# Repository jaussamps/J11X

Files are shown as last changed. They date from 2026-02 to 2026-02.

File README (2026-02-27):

     This is a basic analog test rig for J112/3 JFETs, for determining
     V_GS(off) and I_DSS of specific samples. The design can easily be
     modified to test other N-type depletion-mode families by changing
     power rails, etc. as needed to account for their characteristics.

     As always, this design is free for you to use as you see fit, but
     you do so at your own risk: I provide no warranties of any kind.

                                     --- Charles E. Youse (@jaussamps)

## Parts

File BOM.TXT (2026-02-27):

BILL OF MATERIALS ----------------  J11X  ------------------------ REV A 02/26

C1-C4           220uF 16V 20% ELEC      VALUEPRO ECA-1CM221-JVP
                (6.3 x 11 x 2.5mm)      [JC:198872]

F1              FUSE 30mA 250V PTC      YAGEO BK250-030-DZ
                                        [DK:13-BK250-030-DZ-ND]

D1,D2           1N4007                  [JC:36011]

D3              LED 30mA 2.1V           LITEON LTL-4233
                                        [DK:160-1130-ND JC:697653]

J1*             120VAC MAINS

P1*             1K OHM LINEAR 500mW     ALPHA RV24AF-10-15R1-B1K-3-100
                                        [JC:255485]

Q1              3-PIN 0.1-INCH SOCKET   OMRON XR2C-0311-N
                                        [DK:Z8777-ND]

R1              470 OHM 5% 1W           TECONN ROX1SJ470R
                                        [DK:A106019CT-ND]

SW1*            SPST SWITCH 120VAC

T1              115VAC/6VAC 0.35VA      ZETTLER BV201S06003A
                POWER TRANSFORMER       [DK:3388-BV201S06003A-ND]

------------------------------------------------------------------------------

[QTY 1]         PCB MOUNTING KIT        [JC:106551]

[QTY 1]         METAL ENCLOSURE         [JC:208911]

        Items above marked (*) are chassis-mounted. Footprints
        on the PCB are [combinations of] these terminal blocks:

[QTY 3]         2-PIN TERMINAL BLOCK    ONSHORE OSTTC022162
                                        [DK:ED2609-ND]

[QTY 2]         3-PIN TERMINAL BLOCK    ONSHORE OSTTC032162
                                        [DK:ED2610-ND]

---------------------------------------------------------- vi: ts=4 expandtab:

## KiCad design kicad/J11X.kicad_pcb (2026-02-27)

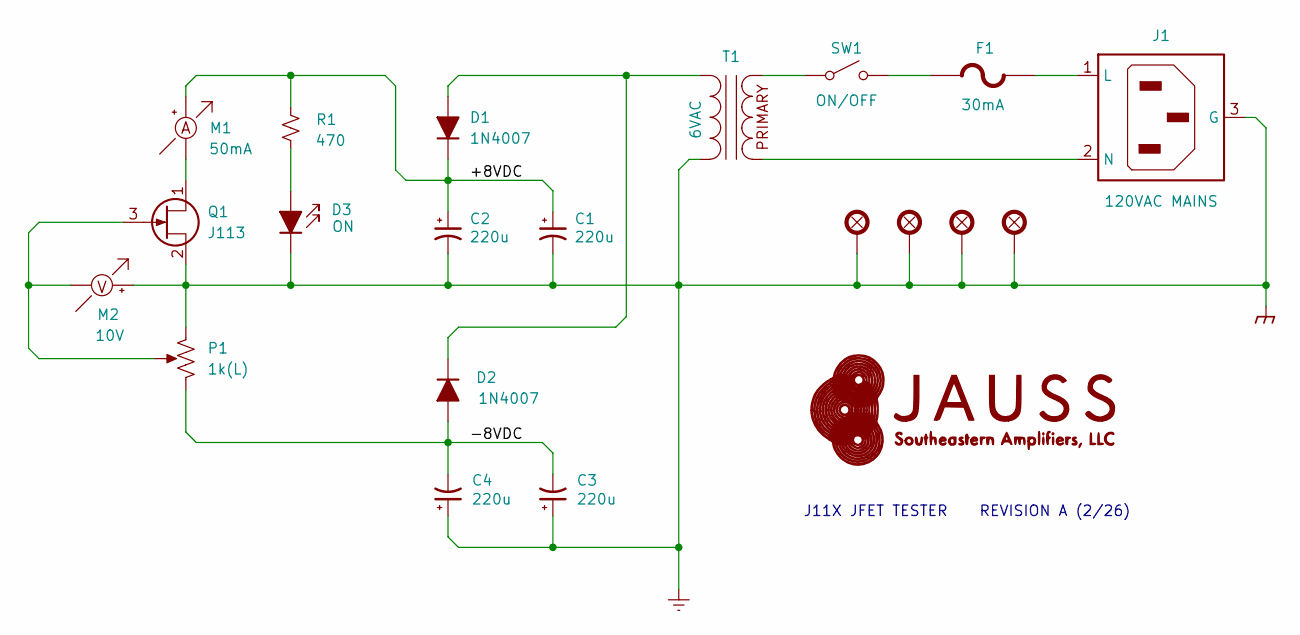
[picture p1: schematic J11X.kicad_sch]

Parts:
C1, C2, C3, C4: 220u; C-POL-RAD-6.3X2.5
D1, D2: 1N4007; D-DO41
D3: LED; D-LITEON-LTL-4233
F1: 30mA; F-YAGEO-BK250-030-DZ
G1: LOGO
H1, H2, H3, H4: H-NO-6-METAL
J1: J-ONSHORE-OSTTC032162
M1: 50mA; J-ONSHORE-OSTTC022162
M2: 10V; J-ONSHORE-OSTTC022162
P1: 1k(L); J-ONSHORE-OSTTC032162
Q1: J113; Q-TO92-WIDE
R1: 470; R-TECONN-ROX1S
SW1: J-ONSHORE-OSTTC022162
T1: 6VAC; T-ZETTLER-BV201S06003A

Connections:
/+8VDC: C1.1, C2.1, D1.1 (K), M1.1 (+), R1.1
/-8VDC: C3.2, C4.2, D2.2 (A), P1.3
=CHASSIS: C1.2, C2.2, C3.1, C4.1, D3.1 (K), H1.1, H2.1, H3.1, H4.1, J1.3 (G), M2.1 (+), P1.1, Q1.2 (S), T1.4 (S)
unnamed: D1.2 (A), D2.1 (K), T1.3 (S)
unnamed: D3.2 (A), R1.2
unnamed: F1.1 (A), SW1.2 (B)
unnamed: F1.2 (B), J1.1 (L)
unnamed: J1.2 (N), T1.2
unnamed: M1.2 (-), Q1.1 (D)
unnamed: M2.2 (-), P1.2, Q1.3 (G)
unnamed: SW1.1 (A), T1.1

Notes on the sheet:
J11X JFET TESTER REVISION A (2/26)

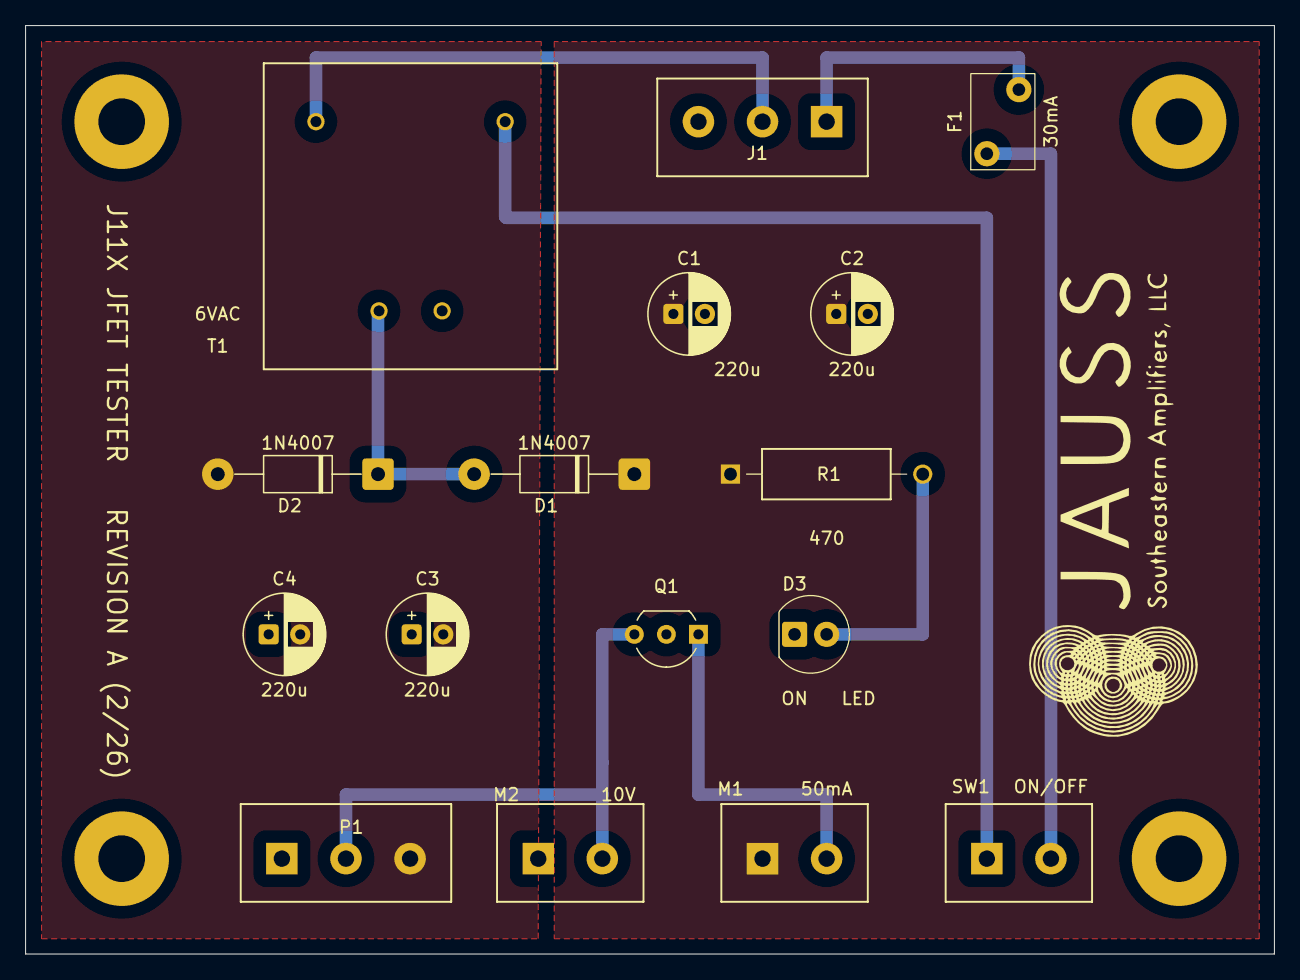
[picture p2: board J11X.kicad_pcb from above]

Board: 2 copper layers, 99.0 x 73.6 mm, 21 parts (0 on the bottom side), 11 nets.
